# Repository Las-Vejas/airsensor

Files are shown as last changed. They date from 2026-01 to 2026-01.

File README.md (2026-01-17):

# かぜ (kaze)

A surrounding sensor that measures a bunch of things!
Heres a list of what it can measure:
 - Temperature (BME680)
 - Humidity (BME680)
 - Pressure (BME680)
 - CO<sub>2</sub> (BME680) (therefore AQI too)
 - lux (TSL2561)
 - and a couple more...

It is powered by the ESP32-C6 module and supports IoT protocols like Zigbee, Wi-fi, Bluetooth and Thread.
The software (that I will eventually write) will be for ESPHome as its very easy to set up IoT and home devices that way with the help of Home Assistant.

The biggest cost for this project would be the BME680 sensor as it costs about 10$

## Images
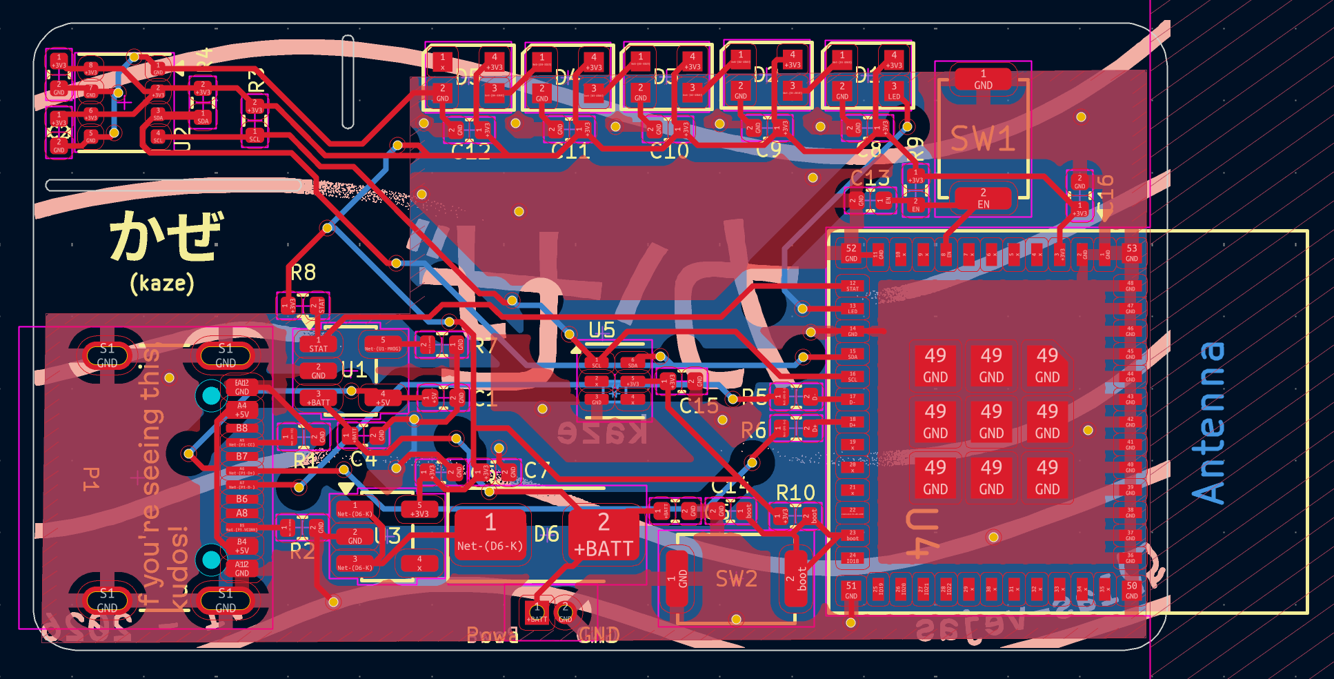
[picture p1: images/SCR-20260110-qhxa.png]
  
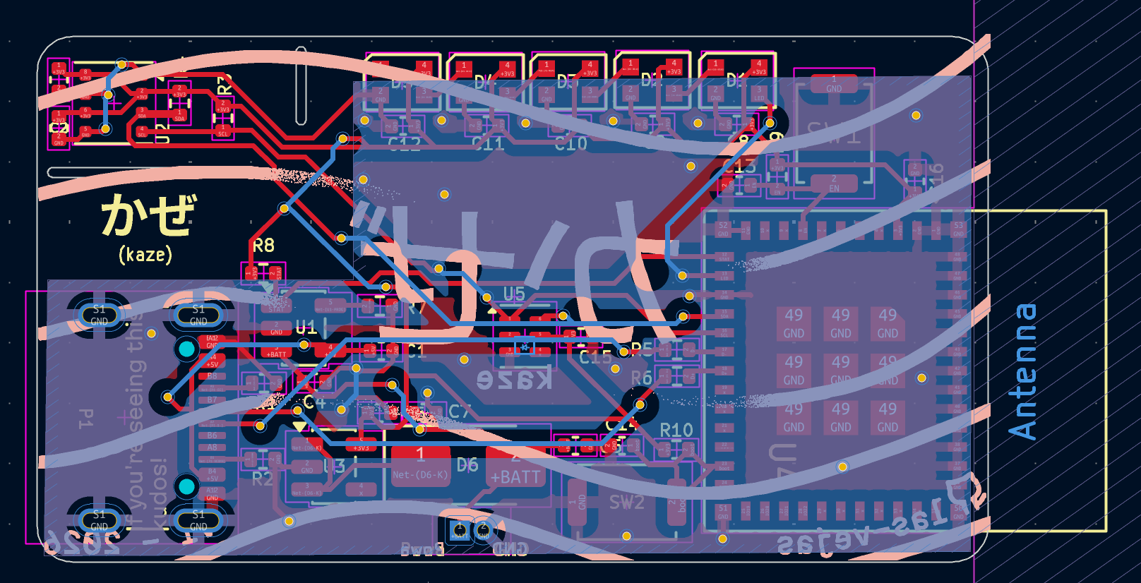
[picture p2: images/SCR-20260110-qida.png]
  
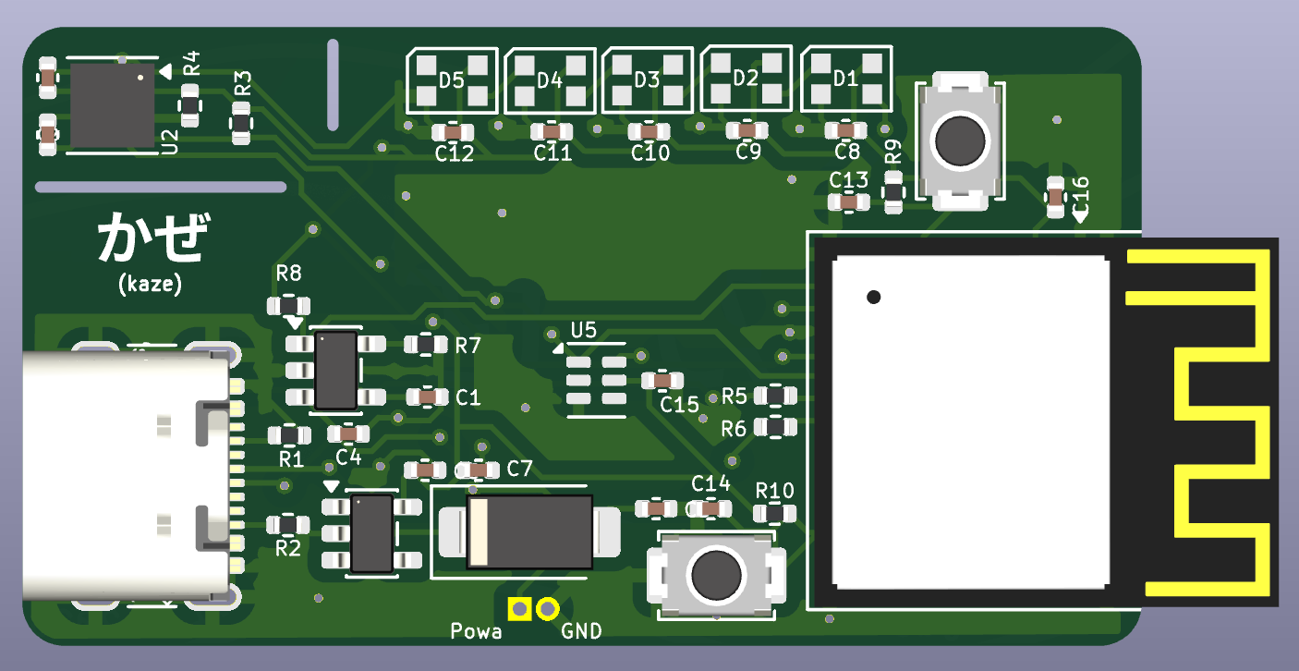
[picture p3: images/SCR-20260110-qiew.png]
  
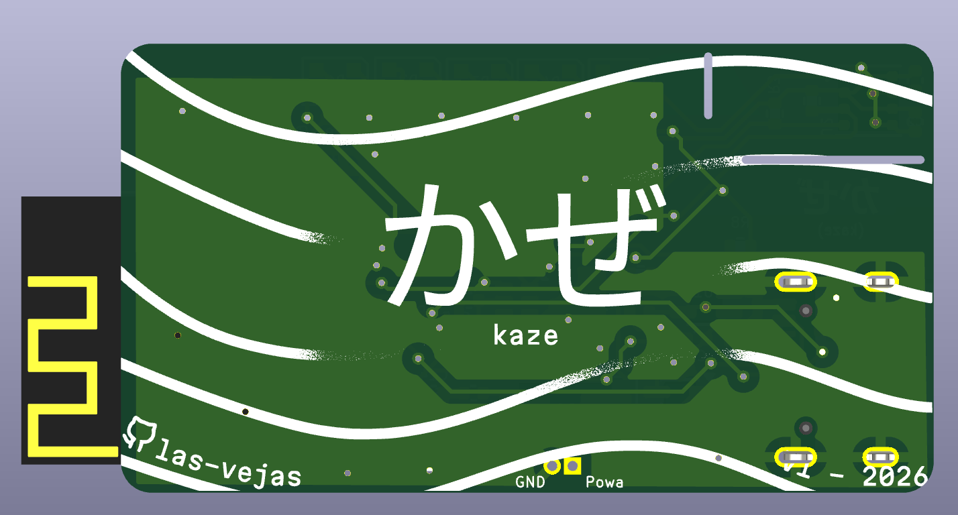
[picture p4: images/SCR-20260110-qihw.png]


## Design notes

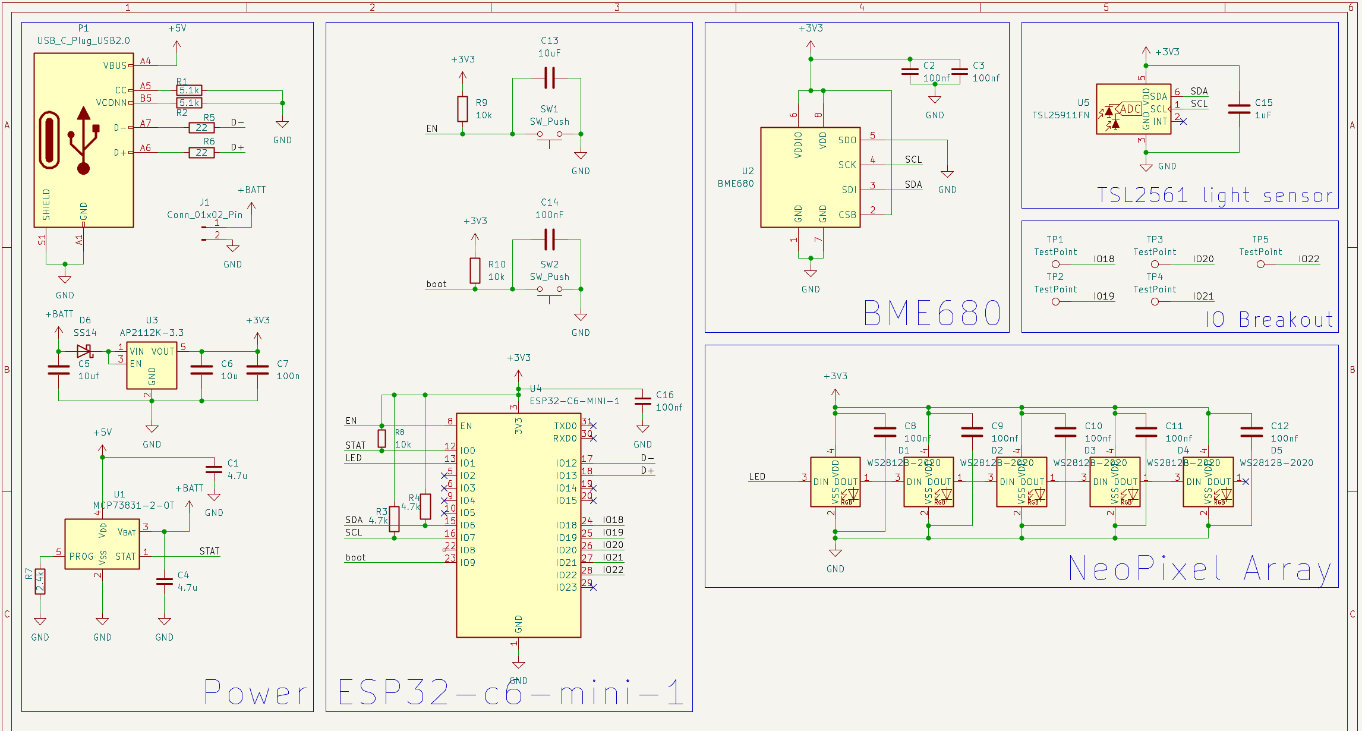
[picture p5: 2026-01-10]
images/SCR-20260110-qinx.png

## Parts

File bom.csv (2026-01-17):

BOM
JLCPCB BOM
Index | Item | Price | Note
1 | PCB from JLCPCB | 2.10 $US
2 | Stencil | 7.00 $US
3 | JLCPCB Shipping | 26.55 $US | Cheapest possible. (Global Standard Direct Line), possible to reduce in half if ordered with other project
LCSC BOM
Mrf# | Mfr. | Order Qty. | Unit Price(USD) | Ext.Price(USD) | LCSC# | Package | Mult | Description | Product Link
TYPE-C 16PIN 2MD(073) | SHOU HAN | 20 | 0.0600 | 1.20 | C2765186 | SMD | 20 | USB-C (USB TYPE-C) Receptacle Connector 16 Position Surface Mount, Right Angle | https://www.lcsc.com/product-detail/C2765186.html
ESP32-C6-MINI-1-N4 | ESPRESSIF | 2 | 4.0436 | 8.09 | C5736265 | SMD-53P | 1 | 2.4GHz ESP32-C6FH4 On-board PCB Antenna -99.2dBm SMD-53P RF Transceiver Modules and Modems RoHS | https://www.lcsc.com/product-detail/C5736265.html
BME680 | Bosch | 1 | 9.8543 | 9.85 | C125972 | LGA-8 | 1 | 30Kpa~1.1bar Temperature Sensor LGA-8 Specialized Sensors RoHS | https://www.lcsc.com/product-detail/C125972.html
SKRKAEE020 | ALPSALPINE | 5 | 0.1298 | 0.65 | C115357 | SMD,3.9x2.9mm | 5 | Tactile Switch SPST 2mm 3.9mm x 2.9mm Surface Mount | https://www.lcsc.com/product-detail/C115357.html
TSL25911FN | AMS | 3 | 1.8060 | 5.42 | C176812 | DFN-6(2x2.2) | 1 | I2C 2.7V~3.6V DFN-6(2x2.2) Ambient Light, IR, UV Sensors RoHS | https://www.lcsc.com/product-detail/C176812.html
MCP73831T-2ACI/OT | MICROCHIP | 2 | 0.7279 | 1.46 | C424093 | SOT-23-5 | 1 | 3.75V~6V Lithium Battery 1 550mA SOT-23-5 Battery Chargers ICs RoHS | https://www.lcsc.com/product-detail/C424093.html
CL05B104KP5VPNC | Samsung Electro-Mechanics | 100 | 0.0049 | 0.49 | C16193311 | 0402 | 100 | 100nF ±10% 10V Ceramic Capacitor X7R 0402 | https://www.lcsc.com/product-detail/C16193311.html
CL05A475MO5NUNC | Samsung Electro-Mechanics | 20 | 0.0090 | 0.18 | C318563 | 0402 | 20 | 4.7uF ±20% 16V Ceramic Capacitor X5R 0402 | https://www.lcsc.com/product-detail/C318563.html
CL05A106MP6NUN8 | Samsung Electro-Mechanics | 50 | 0.0118 | 0.59 | C3902158 | 0402 | 50 | 10uF ±20% 10V Ceramic Capacitor X5R 0402 | https://www.lcsc.com/product-detail/C3902158.html
RC0402JR-0710KL | YAGEO | 100 | 0.0007 | 0.07 | C60489 | 0402 | 100 | 62.5mW 10kΩ 50V Thick Film Resistor ±100ppm/℃ ±5% 0402 Chip Resistor - Surface Mount RoHS | https://www.lcsc.com/product-detail/C60489.html
RC0402JR-074K7L | YAGEO | 100 | 0.0007 | 0.07 | C105870 | 0402 | 100 | 62.5mW 4.7kΩ 50V Thick Film Resistor ±100ppm/℃ ±5% 0402 Chip Resistor - Surface Mount RoHS | https://www.lcsc.com/product-detail/C105870.html
RC0402FR-0722RL | YAGEO | 100 | 0.0007 | 0.07 | C114765 | 0402 | 100 | 22Ω 62.5mW 50V Thick Film Resistor ±100ppm/℃ ±1% 0402 Chip Resistor - Surface Mount RoHS | https://www.lcsc.com/product-detail/C114765.html
RC0402JR-072K4L | YAGEO | 100 | 0.0007 | 0.07 | C137889 | 0402 | 100 | 62.5mW 2.4kΩ 50V Thick Film Resistor ±100ppm/℃ ±5% 0402 Chip Resistor - Surface Mount RoHS | https://www.lcsc.com/product-detail/C137889.html
RC0402FR-075K1L | YAGEO | 100 | 0.0008 | 0.08 | C105872 | 0402 | 100 | 5.1kΩ 62.5mW 50V Thick Film Resistor ±100ppm/℃ ±1% 0402 Chip Resistor - Surface Mount RoHS | https://www.lcsc.com/product-detail/C105872.html
CL05A105KO5NNNC | Samsung Electro-Mechanics | 100 | 0.0023 | 0.23 | C29266 | 0402 | 100 | 1uF ±10% 16V Ceramic Capacitor X5R 0402 | https://www.lcsc.com/product-detail/C29266.html
WS2812B-2020 | Worldsemi | 10 | 0.0829 | 0.83 | C965555 | SMD,2.2x2mm | 5 | SMD,2.2x2mm LED Addressable, Specialty RoHS | https://www.lcsc.com/product-detail/C965555.html
CL05A105KP5NNNC | Samsung Electro-Mechanics | 100 | 0.0018 | 0.18 | C14445 | 0402 | 100 | 1uF ±10% 10V Ceramic Capacitor X5R 0402 | https://www.lcsc.com/product-detail/C14445.html
AP2112K-3.3TRG1 | TECH PUBLIC | 5 | 0.0936 | 0.47 | C23380830 | SOT-23-5 | 5 | 5.5V Positive Fixed 3.3V SOT-23-5 Voltage Regulators - Linear, Low Drop Out (LDO) Regulators RoHS | https://www.lcsc.com/product-detail/C23380830.html
EST TOTAL :$30.10 + $9.50 shipping (GDSL) - $5.10 discounts = $34.50
Battery | https://www.amazon.fr/-/en/Rechargeable-Battery-802540-800mAh-Quadcopter/dp/B0FR41PF1D | 1 | 6.52 | 6.52
TOTAL = 34.5+26.55+7+2.1+6.52=$76.67

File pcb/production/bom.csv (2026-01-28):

Designator | Footprint | Quantity | Value | LCSC Part #
C1, C10, C12, C13, C14, C15, C16, C2, C5, C8 | 0402 | 10 | 100nF
C11, C17 | 0402 | 2 | 4.7uF
C3, C4 | 0402 | 2 | 1uF
C6, C7 | 0402 | 2 | 10uF
C9 | 0402 | 1 | 22uf
D1, D2, D3, D4, D5 | LED_WS2812B-2020_PLCC4_2.0x2.0mm | 5 | WS2812B-2020
J1 | PinHeader_1x02_P1.00mm_Vertical | 1 | Conn_01x02_Pin
J2 | PinHeader_2x02_P1.00mm_Vertical | 1 | Conn_02x02_Odd_Even
P1 | USB_C_Receptacle_GCT_USB4105-xx-A_16P_TopMnt_Horizontal | 1 | USB_C_Plug_USB2.0
R1, R2 | 0402 | 2 | 5.1k
R10, R3, R6, R7 | 0402 | 4 | 10k
R11 | 0402 | 1 | 2.4k
R4, R5 | 0402 | 2 | 22
R8, R9 | 0402 | 2 | 4.7k
SW1, SW2 | SW_Push_SPST_NO_Alps_SKRK | 2 | SW_Push
U1 | AMS_TSL25911FN | 1 | TSL25911FN
U2 | Bosch_LGA-8_3x3mm_P0.8mm_ClockwisePinNumbering | 1 | BME680
U3 | SOT-23-5 | 1 | AP2112K-3.3
U4 | ESP32-C6-MINI-1 | 1 | ESP32-C6-MINI-1
U5 | SOT-23-5 | 1 | MCP73831-2-OT

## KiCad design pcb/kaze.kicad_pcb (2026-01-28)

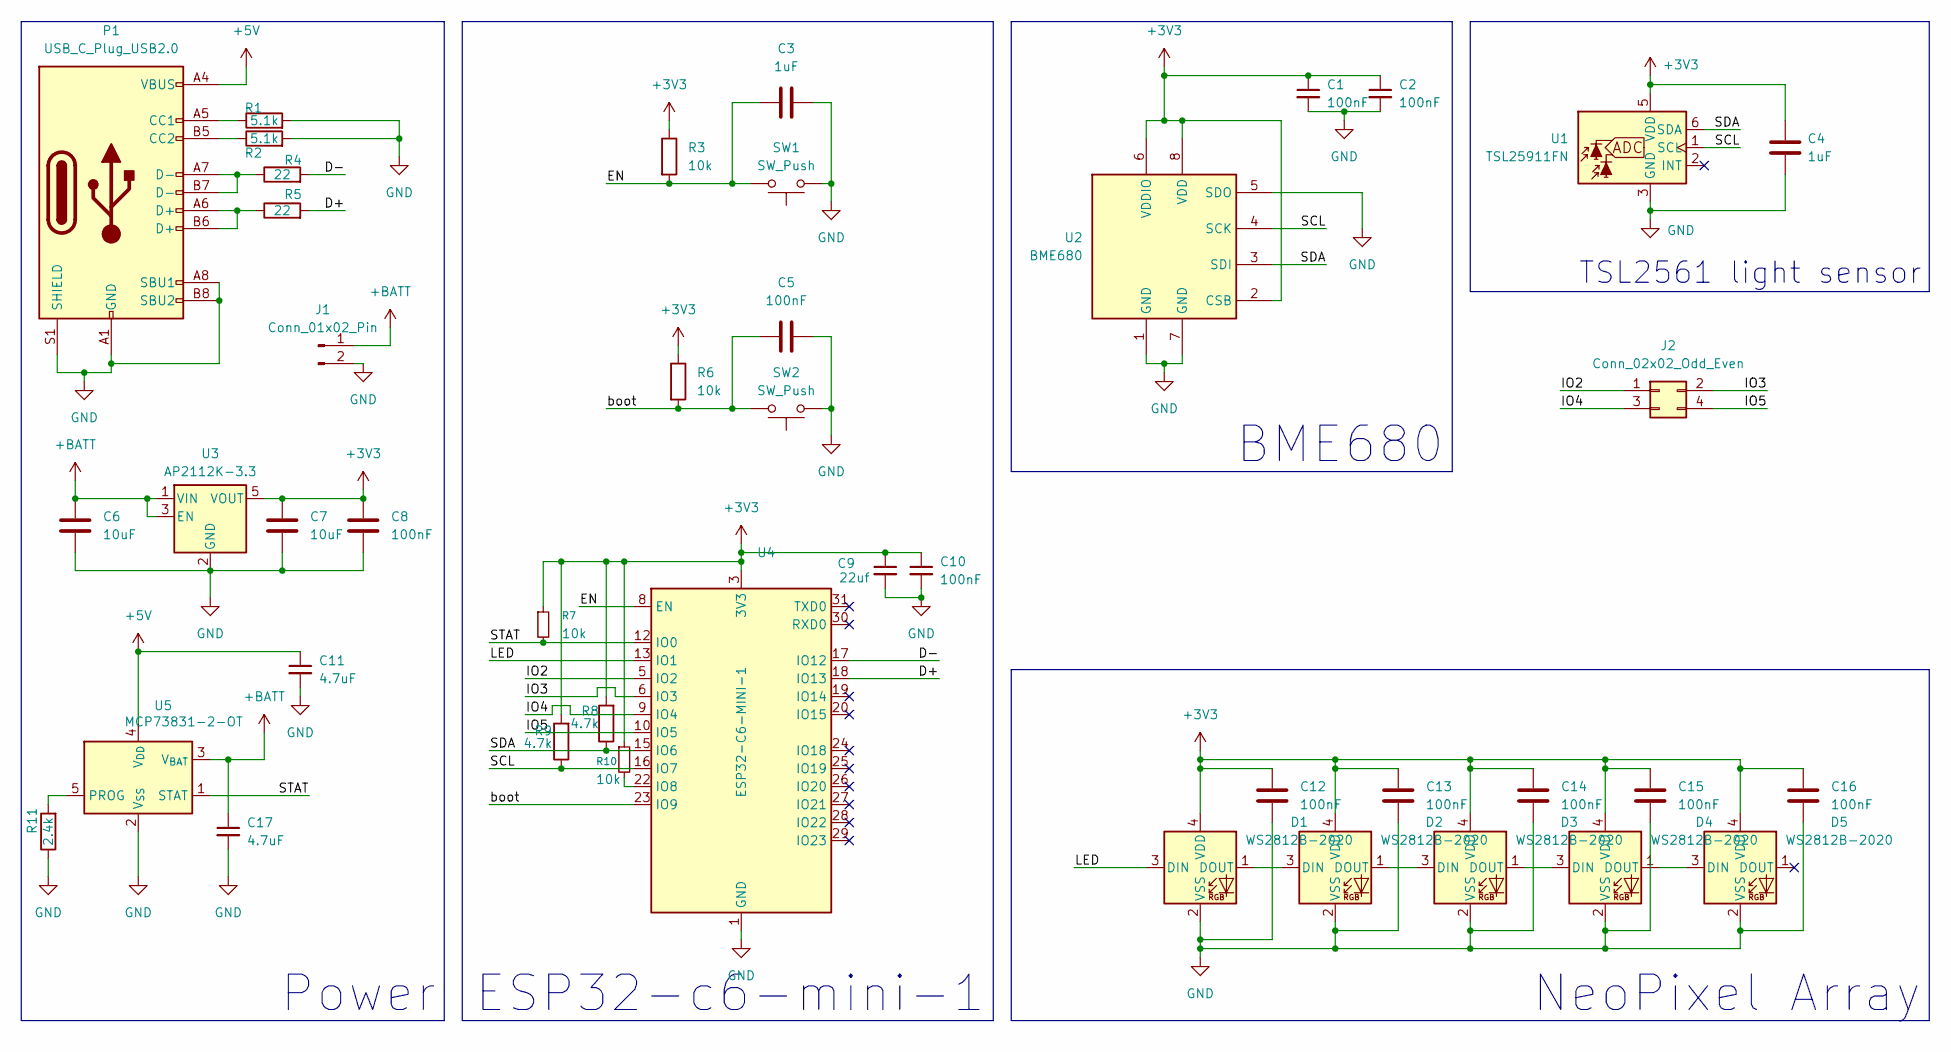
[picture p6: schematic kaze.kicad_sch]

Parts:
C1, C2, C5, C8, C10, C12, C13, C14, C15, C16: 100nF; C_0402_1005Metric
C3, C4: 1uF; C_0402_1005Metric
C6, C7: 10uF; C_0402_1005Metric
C9: 22uf; C_0402_1005Metric
C11, C17: 4.7uF; C_0402_1005Metric
D1, D2, D3, D4, D5: WS2812B-2020; LED_WS2812B-2020_PLCC4_2.0x2.0mm
J1: Conn_01x02_Pin; PinHeader_1x02_P1.00mm_Vertical
J2: Conn_02x02_Odd_Even; PinHeader_2x02_P1.00mm_Vertical
P1: USB_C_Plug_USB2.0; USB_C_Receptacle_GCT_USB4105-xx-A_16P_TopMnt_Horizontal
R1, R2: 5.1k; R_0402_1005Metric
R3, R6, R7, R10: 10k; R_0402_1005Metric
R4, R5: 22; R_0402_1005Metric
R8, R9: 4.7k; R_0402_1005Metric
R11: 2.4k; R_0402_1005Metric
SW1, SW2: SW_Push; SW_Push_SPST_NO_Alps_SKRK
U1: TSL25911FN; AMS_TSL25911FN
U2: BME680; Bosch_LGA-8_3x3mm_P0.8mm_ClockwisePinNumbering
U3: AP2112K-3.3; SOT-23-5
U4: ESP32-C6-MINI-1
U5: MCP73831-2-OT; SOT-23-5

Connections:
+3V3: C1.1, C2.1, C4.1, C7.1, C8.1, C9.1, C10.1, C12.1, C13.1, C14.1, C15.1, C16.1, D1.4 (VDD), D2.4 (VDD), D3.4 (VDD), D4.4 (VDD), D5.4 (VDD), R3.1, R6.1, R7.1, R8.2, R9.2, R10.1, U1.5 (VDD), U2.2 (CSB), U2.6 (VDDIO), U2.8 (VDD), U3.5 (VOUT), U4.3 (3V3)
+5V: C11.1, P1.A4 (VBUS), P1.A9 (VBUS), P1.B4 (VBUS), P1.B9 (VBUS), U5.4 (V_{DD})
+BATT: C6.1, C17.1, J1.1, U3.1 (VIN), U3.3 (EN), U5.3 (V_{BAT})
/D+: R5.2, U4.18 (IO13)
/D-: R4.2, U4.17 (IO12)
/EN: C3.1, R3.2, SW1.2, U4.8 (EN)
/IO2: J2.1, U4.5 (IO2)
/IO3: J2.2, U4.6 (IO3)
/IO4: J2.3, U4.9 (IO4)
/IO5: J2.4, U4.10 (IO5)
/LED: D1.3 (DIN), U4.13 (IO1)
/SCL: R9.1, U1.1 (SCL), U2.4 (SCK), U4.16 (IO7)
/SDA: R8.1, U1.6 (SDA), U2.3 (SDI), U4.15 (IO6)
/STAT: R7.2, U4.12 (IO0), U5.1 (STAT)
/boot: C5.1, R6.2, SW2.2, U4.23 (IO9)
GND: C1.2, C2.2, C3.2, C4.2, C5.2, C6.2, C7.2, C8.2, C9.2, C10.2, C11.2, C12.2, C13.2, C14.2, C15.2, C16.2, C17.2, D1.2 (VSS), D2.2 (VSS), D3.2 (VSS), D4.2 (VSS), D5.2 (VSS), J1.2, P1.A1 (GND), P1.A8 (SBU1), P1.A12 (GND), P1.B1 (GND), P1.B8 (SBU2), P1.B12 (GND), P1.S1 (SHIELD), R1.2, R2.2, R11.1, SW1.1, SW2.1, U1.3 (GND), U2.1 (GND), U2.5 (SDO), U2.7 (GND), U3.2 (GND), U4.1 (GND), U4.2 (GND), U4.11 (GND), U4.14 (GND), U4.36 (GND), U4.37 (GND), U4.38 (GND), U4.39 (GND), U4.40 (GND), U4.41 (GND), U4.42 (GND), U4.43 (GND), U4.44 (GND), U4.45 (GND), U4.46 (GND), U4.47 (GND), U4.48 (GND), U4.49 (GND), U4.50 (GND), U4.51 (GND), U4.52 (GND), U4.53 (GND), U5.2 (V_{SS})
unnamed: D1.1 (DOUT), D2.3 (DIN)
unnamed: D2.1 (DOUT), D3.3 (DIN)
unnamed: D3.1 (DOUT), D4.3 (DIN)
unnamed: D4.1 (DOUT), D5.3 (DIN)
unnamed: P1.A5 (CC1), R1.1
unnamed: P1.B5 (CC2), R2.1
unnamed: P1.A6 (D+), P1.B6 (D+), R5.1
unnamed: P1.A7 (D-), P1.B7 (D-), R4.1
unnamed: R10.2, U4.22 (IO8)
unnamed: R11.2, U5.5 (PROG)

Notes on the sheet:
TSL2561 light sensor
ESP32-c6-mini-1
NeoPixel Array
Power
BME680

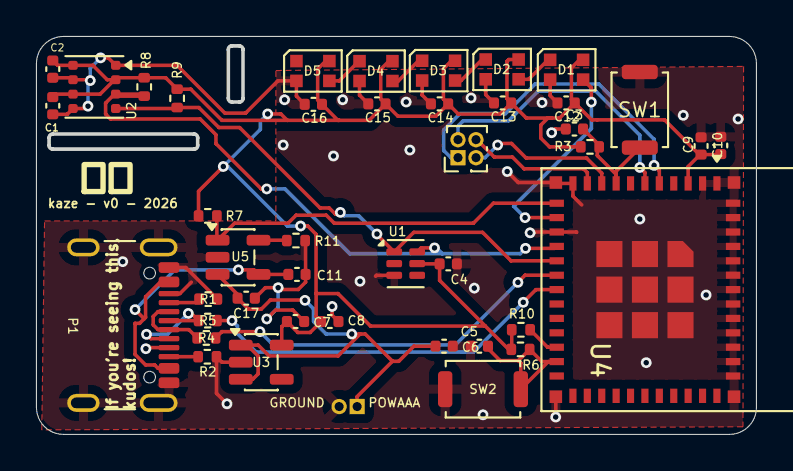
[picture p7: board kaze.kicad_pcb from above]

Board: 2 copper layers, 40.0 x 22.1 mm, 43 parts (1 on the bottom side), 26 nets.

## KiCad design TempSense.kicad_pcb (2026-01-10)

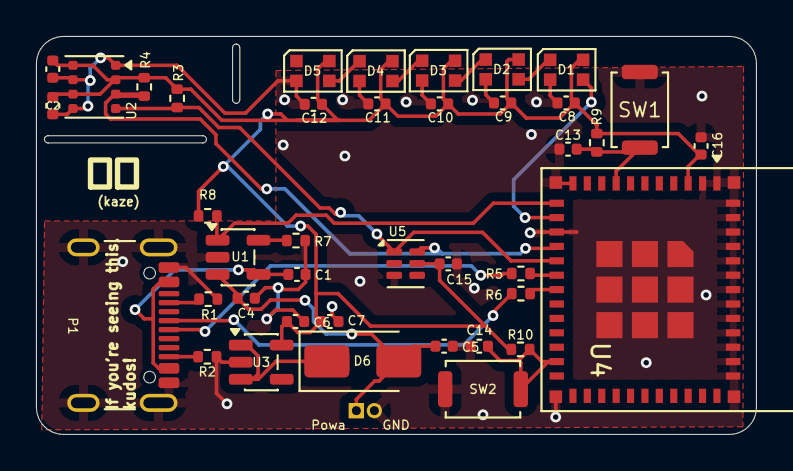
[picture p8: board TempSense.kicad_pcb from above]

Board: 2 copper layers, 40.0 x 22.1 mm, 41 parts (0 on the bottom side), 22 nets.

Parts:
C1, C4: 4.7u; C_0402_1005Metric
C2, C3, C8, C9, C10, C11, C12, C16: 100nf; C_0402_1005Metric
C5: 10uf; C_0402_1005Metric
C6: 10u; C_0402_1005Metric
C7: 100n; C_0402_1005Metric
C13: 10uF; C_0402_1005Metric
C14: 100nF; C_0402_1005Metric
C15: 1uF; C_0402_1005Metric
D1, D2, D3, D4, D5: WS2812B-2020; LED_WS2812B-2020_PLCC4_2.0x2.0mm
D6: SS14; D_SMA
J1: Conn_01x02_Pin; PinHeader_2x01_P1.00mm_Vertical
P1: USB_C_Plug_USB2.0; USB_C_Receptacle_GCT_USB4105-xx-A_16P_TopMnt_Horizontal
R1, R2: 5.1k; R_0402_1005Metric
R3, R4: 4.7k; R_0402_1005Metric
R5, R6: 22; R_0402_1005Metric
R7: 2.4k; R_0402_1005Metric
R8, R9, R10: 10k; R_0402_1005Metric
SW1, SW2: SW_Push; SW_Push_SPST_NO_Alps_SKRK
U1: MCP73831-2-OT; SOT-23-5
U2: BME680; Bosch_LGA-8_3x3mm_P0.8mm_ClockwisePinNumbering
U3: AP2112K-3.3; SOT-23-5
U4: ESP32-C6-MINI-1
U5: TSL25911FN; AMS_TSL25911FN

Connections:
+3V3: C2.1, C3.1, C6.1, C7.1, C8.1, C9.1, C10.1, C11.1, C12.1, C15.1, C16.1, D1.4 (VDD), D2.4 (VDD), D3.4 (VDD), D4.4 (VDD), D5.4 (VDD), R3.2, R4.2, R8.1, R9.1, R10.1, U2.2 (CSB), U2.6 (VDDIO), U2.8 (VDD), U3.5 (VOUT), U4.3 (3V3), U5.5 (VDD)
+5V: C1.1, P1.A4 (VBUS), P1.A9 (VBUS), P1.B4 (VBUS), P1.B9 (VBUS), U1.4 (V_{DD})
+BATT: C4.1, C5.1, D6.2 (A), J1.1, U1.3 (V_{BAT})
/D+: R6.2, U4.18 (IO13)
/D-: R5.2, U4.17 (IO12)
/EN: C13.1, R9.2, SW1.2, U4.8 (EN)
/LED: D1.3 (DIN), U4.13 (IO1)
/SCL: R3.1, U2.4 (SCK), U4.16 (IO7), U5.1 (SCL)
/SDA: R4.1, U2.3 (SDI), U4.15 (IO6), U5.6 (SDA)
/STAT: R8.2, U1.1 (STAT), U4.12 (IO0)
/boot: C14.1, R10.2, SW2.2, U4.23 (IO9)
GND: C1.2, C2.2, C3.2, C4.2, C5.2, C6.2, C7.2, C8.2, C9.2, C10.2, C11.2, C12.2, C13.2, C14.2, C15.2, C16.2, D1.2 (VSS), D2.2 (VSS), D3.2 (VSS), D4.2 (VSS), D5.2 (VSS), J1.2, P1.A1 (GND), P1.A12 (GND), P1.B1 (GND), P1.B12 (GND), P1.S1 (SHIELD), R1.2, R2.2, R7.1, SW1.1, SW2.1, U1.2 (V_{SS}), U2.1 (GND), U2.5 (SDO), U2.7 (GND), U3.2 (GND), U4.1 (GND), U4.2 (GND), U4.11 (GND), U4.14 (GND), U4.36 (GND), U4.37 (GND), U4.38 (GND), U4.39 (GND), U4.40 (GND), U4.41 (GND), U4.42 (GND), U4.43 (GND), U4.44 (GND), U4.45 (GND), U4.46 (GND), U4.47 (GND), U4.48 (GND), U4.49 (GND), U4.50 (GND), U4.51 (GND), U4.52 (GND), U4.53 (GND), U5.3 (GND)
unnamed: D1.1 (DOUT), D2.3 (DIN)
unnamed: D2.1 (DOUT), D3.3 (DIN)
unnamed: D3.1 (DOUT), D4.3 (DIN)
unnamed: D4.1 (DOUT), D5.3 (DIN)
unnamed: D6.1 (K), U3.1 (VIN), U3.3 (EN)
unnamed: P1.A5 (CC), R1.1
unnamed: P1.A6 (D+), R6.1
unnamed: P1.A7 (D-), R5.1
unnamed: P1.B5 (VCONN), R2.1
unnamed: R7.2, U1.5 (PROG)

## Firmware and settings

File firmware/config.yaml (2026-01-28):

esphome:
  name: kaze-unit

esp32:
  board: esp32-c6-devkitc-1 # Best match for C6-Mini-1
  framework:
    type: esp-idf

i2c:
  sda: 6  # Replace with your actual SDA pin
  scl: 7  # Replace with your actual SCL pin

sensor:
  - platform: bme680
    temperature:
      name: "Room Temperature"
    pressure:
      name: "Atmospheric Pressure"
    humidity:
      name: "Relative Humidity"
    gas_resistance:
      name: "Gas Resistance"
    address: 0x77

  - platform: tsl2561
    name: "Ambient Light"
    address: 0x39

light:
  - platform: neopixelbus
    type: GRB
    pin: 8 # Replace with your LED data pin
    num_leds: 5
    name: "Kaze Status LEDs"

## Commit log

2026-01-10 almost finished
    [TempSense.kicad_pcb, TempSense.kicad_sch]
2026-01-14 pcb stuff
    [bom.csv, digikey-bom.csv, kaze-v1_bom.csv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]
2026-01-17 bom update
    [bom.csv]
